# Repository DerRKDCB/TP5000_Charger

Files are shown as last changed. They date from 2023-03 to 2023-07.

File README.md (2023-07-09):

# TP5000_Charger

## TODO

### V1.1

* [x] Test under voltage and short current feature
* [x] rename from LiFePo4 Charger to Lithium Battery Charger
* [x] make select-able between LiFePo4 and LiPo, schematic OK
* [x] fix LEDs to Vin instead of GND, schematic OK
* [x] remove component labels
* [x] tighter layout
* [x] mounting holes in schematic
* [x] smaller solder connections, schematic footprints OK
* [x] USB C side B D+ and D- connections, schematic OK
* [x] change 0805 handsolder to 0805

### V1.2

* [x] missing ground connection C3
* [x] test with lipo
* [x] update silkscreen and schematic version number
* [x] plot gerber

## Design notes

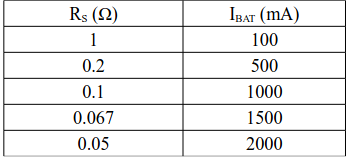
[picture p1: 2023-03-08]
datasheets/tp5000_set_current_resistor.png

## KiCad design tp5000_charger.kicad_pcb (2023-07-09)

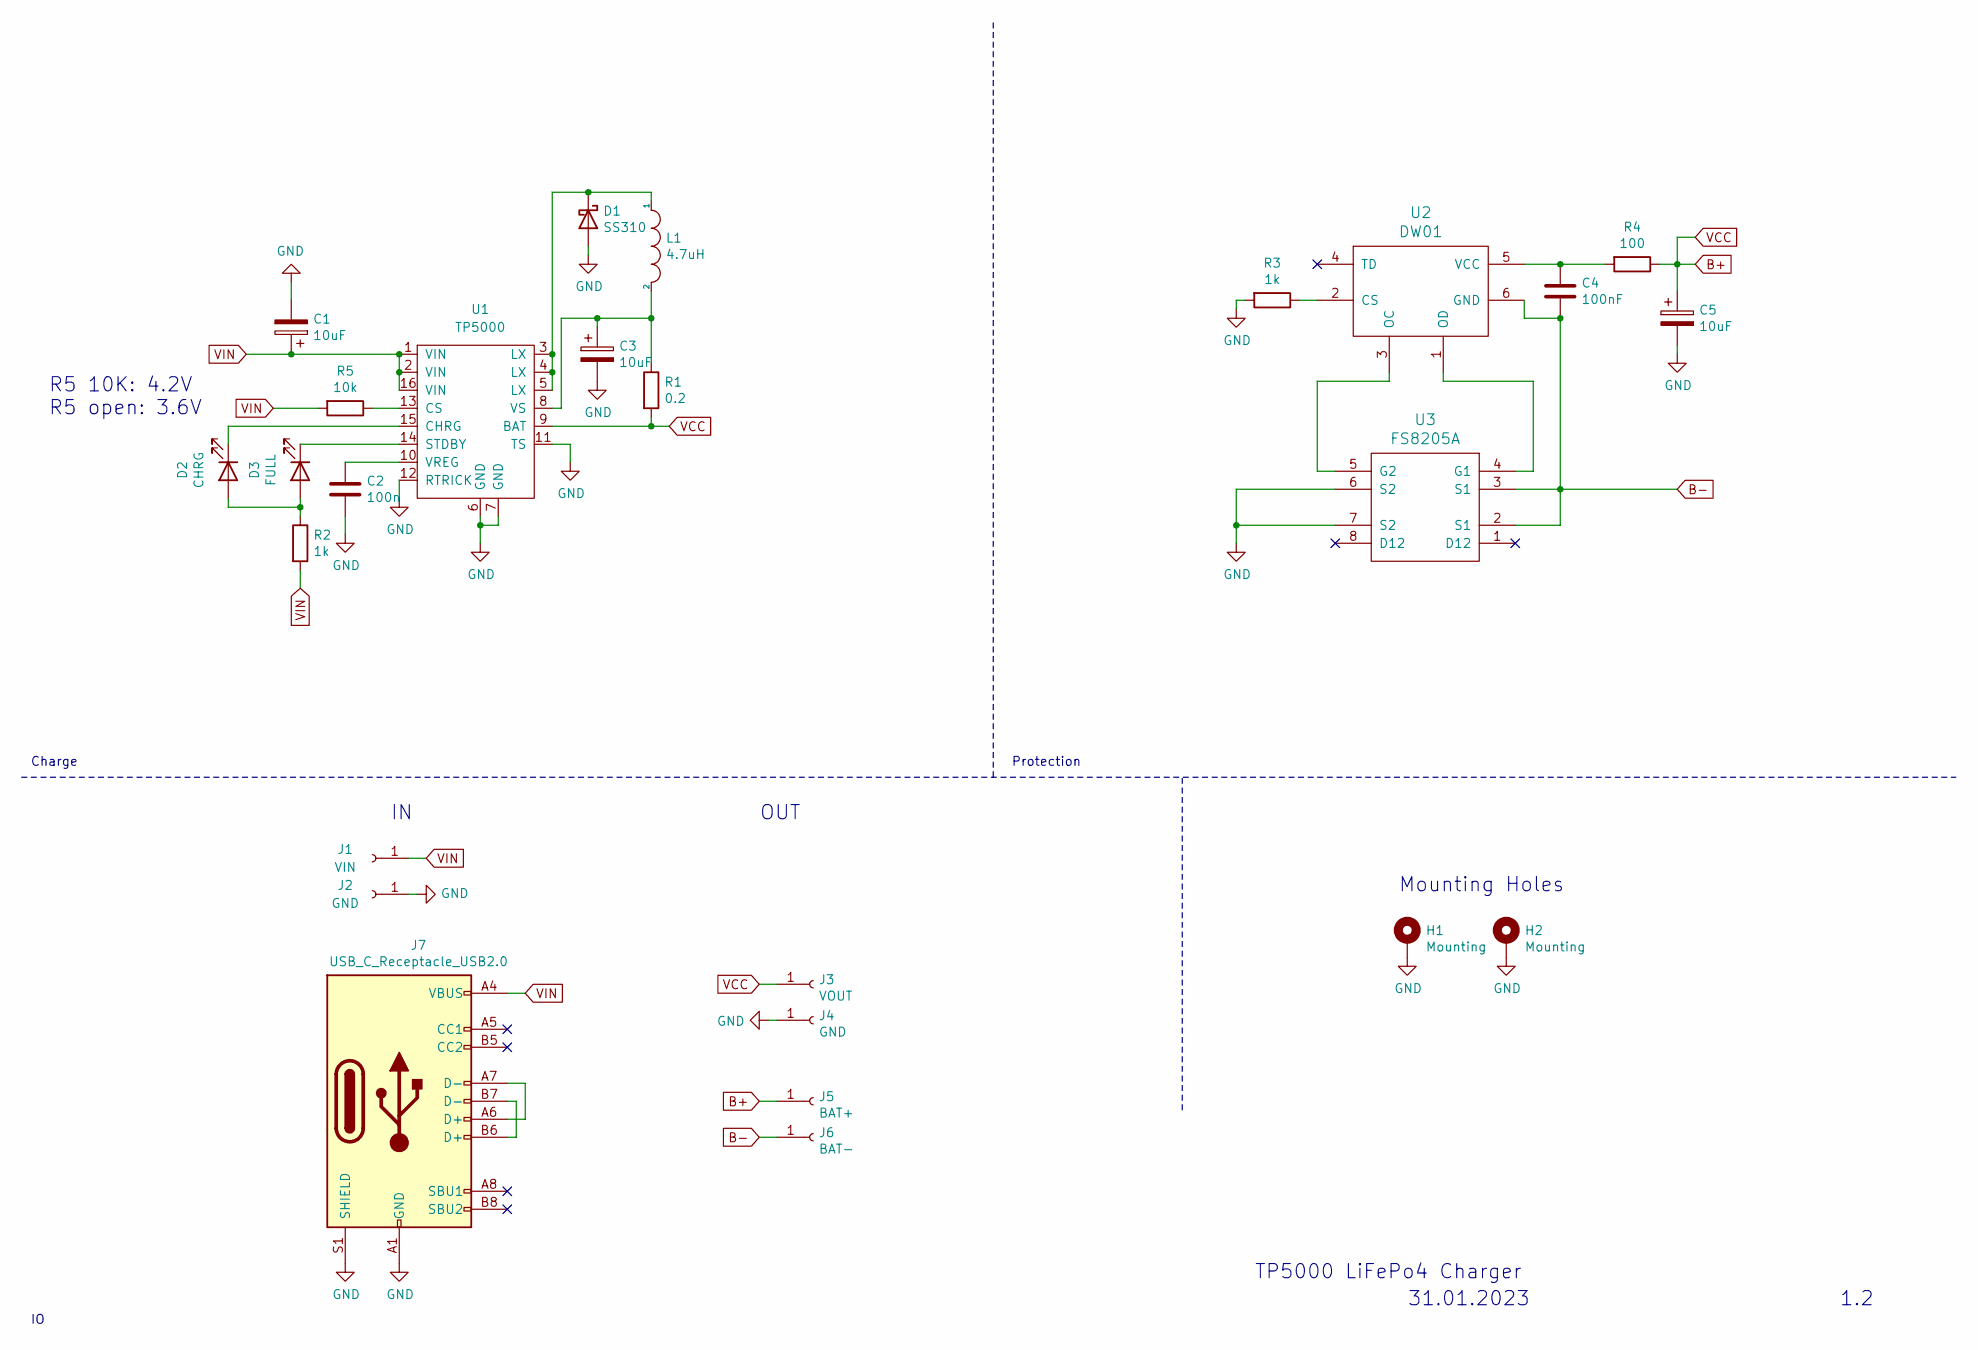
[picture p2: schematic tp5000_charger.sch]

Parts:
C1, C3, C5: 10uF; CP_EIA-3216-12_Kemet-S
C2: 100n; C_0805_2012Metric
C4: 100nF; C_0805_2012Metric
D1: SS310; D_SMA
D2: CHRG; LED_0805_2012Metric
D3: FULL; LED_0805_2012Metric
H1, H2: Mounting; MountingHole_2.7mm_M2.5_DIN965_Pad
J1: VIN; TestPoint_THTPad_2.5x2.5mm_Drill1.2mm
J2, J4: GND; TestPoint_THTPad_2.5x2.5mm_Drill1.2mm
J3: VOUT; TestPoint_THTPad_2.5x2.5mm_Drill1.2mm
J5: BAT+; TestPoint_THTPad_2.5x2.5mm_Drill1.2mm
J6: BAT-; TestPoint_THTPad_2.5x2.5mm_Drill1.2mm
J7: USB_C_Receptacle_USB2.0; USB_C_Receptacle_Palconn_UTC16-G
L1: 4.7uH; L_Taiyo-Yuden_NR-50xx
R1: 0.2; R_1206_3216Metric_Pad1.30x1.75mm_HandSolder
R2, R3: 1k; R_0805_2012Metric
R4: 100; R_0805_2012Metric
R5: 10k; R_0805_2012Metric
U1: TP5000; QFN-16-1EP_4x4mm_P0.65mm_EP2.1x2.1mm
U2: DW01; SOT-23-6
U3: FS8205A; TSSOP-8_4.4x3mm_P0.65mm

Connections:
B+: C5.1, J3.1, J5.1, R1.2, R4.1, U1.9 (BAT)
B-: C4.2, J6.1, U2.6 (GND), U3.2 (S1), U3.3 (S1)
GND: C1.2, C2.2, C3.2, C5.2, D1.2 (A), H1.1, H2.1, J2.1, J4.1, J7.A1 (GND), J7.A12 (GND), J7.B1 (GND), J7.B12 (GND), J7.S1 (SHIELD), R3.2, U1.6 (GND), U1.7 (GND), U1.11 (TS), U1.12 (RTRICK), U3.6 (S2), U3.7 (S2)
unnamed: C2.1, U1.10 (VREG)
unnamed: C3.1, L1.2, R1.1, U1.8 (VS)
unnamed: C4.1, R4.2, U2.5 (VCC)
unnamed: D1.1 (K), L1.1, U1.3 (LX), U1.4 (LX), U1.5 (LX)
unnamed: D2.1 (K), U1.15 (CHRG)
unnamed: D2.2 (A), D3.2 (A), R2.1
unnamed: D3.1 (K), U1.14 (STDBY)
unnamed: J7.A6 (D+), J7.A7 (D-)
unnamed: J7.B6 (D+), J7.B7 (D-)
unnamed: R3.1, U2.2 (CS)
unnamed: R5.1, U1.13 (CS)
unnamed: U2.1 (OD), U3.4 (G1)
unnamed: U2.3 (OC), U3.5 (G2)
VIN: C1.1, J1.1, J7.A4 (VBUS), J7.A9 (VBUS), J7.B4 (VBUS), J7.B9 (VBUS), R2.2, R5.2, U1.1 (VIN), U1.2 (VIN), U1.16 (VIN)

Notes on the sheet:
Charge
Protection
1.2
31.01.2023
TP5000 LiFePo4 Charger
R5 10K: 4.2V R5 open: 3.6V
Mounting Holes
OUT

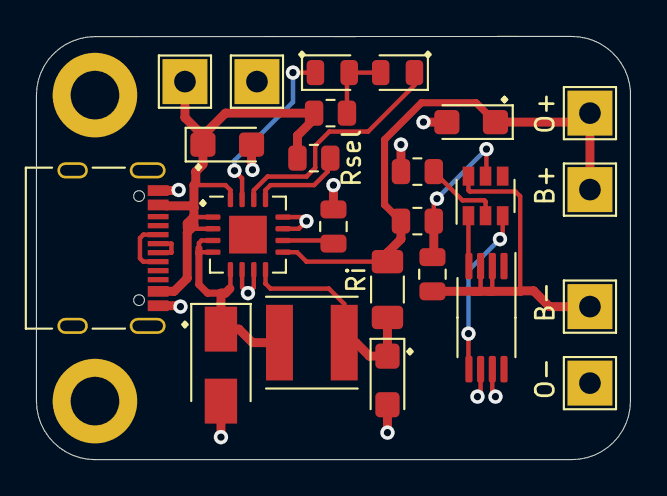
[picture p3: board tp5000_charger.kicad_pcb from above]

Board: 2 copper layers, 33.0 x 23.5 mm, 26 parts (0 on the bottom side), 17 nets.

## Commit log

2023-03-08 changed footprint solder connection in schematic
    [tp5000_lifepo4_charger.sch]
2023-03-14 change file name to tp500_charger
    [tp5000_charger.kicad_pcb, tp5000_charger.sch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]
2023-03-14 select 3.6 vs 4.2V
    [tp5000_charger.sch]
2023-03-14 mounting holes
    [tp5000_charger.sch]
2023-03-14 pcb design V1.1
    [tp5000_charger.kicad_pcb, tp5000_charger.sch]
2023-03-19 layout smaller
    [tp5000_charger.kicad_pcb, tp5000_charger.sch]
2023-03-19 create gerber files
    [tp5000_charger-B_Cu.gbr, tp5000_charger-B_Mask.gbr, tp5000_charger-B_Paste.gbr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]
2023-04-29 gnd connection c3
    [tp5000_charger.kicad_pcb]
2023-04-29 version number 1.2
    [tp5000_charger.kicad_pcb, tp5000_charger.sch]
2023-07-09 generate gerber files
    [tp5000_charger-B_Cu.gbr, tp5000_charger-B_Mask.gbr, tp5000_charger-B_Paste.gbr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]
2023-07-09 polarity indicator d1
    [tp5000_charger-B_Cu.gbr, tp5000_charger-B_Mask.gbr, tp5000_charger-B_Paste.gbr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]
